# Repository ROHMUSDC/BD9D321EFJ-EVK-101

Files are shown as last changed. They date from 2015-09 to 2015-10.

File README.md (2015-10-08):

# BD9D321EFJ-EVK-101 Design Resource Repository
* Hardware Design Files and Documentation for the ROHM BD9D321EFJ-EVK-101 EVK

----
### Description: 
* BD9D321EFJ is a synchronous buck switching regulator with built-in low on-resistance power MOSFETs
* It is capable of providing current of up to 3 A
* The SLLM (TM) control provides excellent efficiency characteristics in light-load conditions which make the product appropriate for equipment and devices that demand minimal standby power consumption
* External phase compensation circuit is not necessary because this device uses a constant on-time control DC/DC converter with high speed response

----
### Repository Contents
* Application Note Folder: Contains Draft Version of EVK Application Note
* Design Files: Contains Board, Gerber, Schematic, and BOM information for this EVK Board
* Measurement Reports Folder: Contains measurement testing information completed for these EVK Boards

----
### Where to Purchase?
* http://www.rohm.com/web/global/distribution/-/dinventory/BD9D321EFJ-EVK-101/sample/0

----
### DISCLAIMER
This Technical Data is protected under copyright laws.

ROHM hereby grants you a nonexclusive, nontransferable license to use this Technical Data 
as long as you abide by the terms and conditions of this DISCLAIMER. 

However, you are not authorized to sell, loan, rent, lease, redistribute or license this Technical Data, 
in whole or in part, or in modified form, to anyone.

You may modify this Technical Data to suit your specific applications, 
but the rights to derivative works and said modifications shall belong to ROHM. 

You may make copies of this Technical Data as necessary for internal use only within your company.

In any case, the latest datasheet is considered the final design guideline and represents 
the only actual performance specifications.

ROHM shall not be responsible for ensuring proper application on all computer systems.
This Technical Data is provided AS IS. ROHM makes no guarantees, either implicitly or explicitly, 
regarding its usability, functionality, accuracy, merchantability, or fitness for a specific purpose.

In addition, you shall take full responsibility for the use of any information acquired from this Technical Data. 

ROHM does not assume warranty of any kind arising from the use of this Technical Data. ACCORDINGLY, 
IN NO EVENT SHALL ROHM BE RESPONSIBLE, WHETHER THROUGH CONTRACT OR TORT LIABILITY, 
FOR ANY DAMAGES (INCLUDING BUT NOT LIMITED TO LOST PROFITS OR OTHER INCIDENTAL, CONSEQUENTAL, 
OR PUNITIVE DAMAGES) ARISING OUT OF OR IN CONNECTION WITH THE USE OR APPLICATION OF THIS Technical Data.

Furthermore, this Technical Data is subject to change without notice.

Unless otherwise expressly provided herein, ROHM does not convey any license under patent rights 
or any other intellectual property rights (including those of third parties).

ROHM is not obligated to provide maintenance or support for the Technical Data.

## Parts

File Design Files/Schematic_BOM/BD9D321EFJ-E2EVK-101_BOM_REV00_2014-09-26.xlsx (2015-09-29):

BD9D321EFJ-E2EVK-101 BOM
Revision: 00
Item | Quantity | Reference | Part | PCB Footprint | DESCRIPTION | MFG1 | MFG1_PART# | DISTR1 | DISTR1_PART# | DNP | Provided by ROHM | ROHM Comment
1 | 1 | C1 | 100pF | C0603 | CAP CER 100PF 50V 5% NP0 0603 | Murata | GRM1885C1H101JA01D | DIGIKEY | 490-1433-2-ND |  | Y
2 | 2 | C2,C10 | 0.1uF | C0603 | CAP CER 0.1UF 50V 10% X7R 0603 | Murata | GRM188R71H104KA93D | DIGIKEY | 490-1519-2-ND |  | Y
3 | 2 | C3,C4 | 10uF | C1206 | CAP CER 10UF 35V 10% X5R 1206 | Murata | GRM31CR6YA106KA12L | DIGIKEY | 490-5524-1-ND |  | Y
4 | 2 | C5,C6 | 22uF | C1210 | CAP CER 22UF 25V 10% X5R 1210 | Murata | GRM32ER61E226KE15L | DIGIKEY | 490-3889-1-ND |  | Y
5 | 1 | C11 | 1uF | C0603 | CAP CER 1UF 25V 10% X7R 0603 | Murata | GRM188R71E105KA12D | Digikey | 490-5307-2-ND |  | Y
6 | 1 | C12 | 3300pF | C0603 | CAP CER 3300PF 50V 10% X7R 0603 | Murata | GRM188R71H332KA01D | Digikey | 490-1503-2-ND |  | Y
7 | 1 | D1 | SMAJ18A | DO-214AC | DIODE TVS 400W 6.8V UNI 5% SMD | Littelfuse Inc | P4SMA6.8A | DIGIKEY | F5656CT-ND |  | N
8 | 1 | J1 | 87224-3 | HDR_THVT_1X3_100 | CONN HEADER VERT .100 3POS 15AU | TE Connectivity | 87224-3 | DIGIKEY | A26545-ND |  | N
9 | 1 | L1 | 2.2uH | SMT_6P9x6P9 | INDUCTOR POWER 2.2UH 9A SMD | Wurth | 744311220 | DIGIKEY | 732-1151-2-ND |  | Y
10 | 1 | R1 | 30k | R0603 | RES 30K OHM 1/10W 1% 0603 SMD | Rohm | MCR03ERTF3002 | DIGIKEY | RHM30KCFTR-ND |  | Y
11 | 1 | R2 | 22k | R0603 | RES 22K OHM 1/10W 1% 0603 SMD | Rohm | MCR03ERTF2202 | DIGIKEY | RHM22.0KCFTR-ND |  | Y
12 | 1 | R3 | 0 | R0603 | RES 0.0 OHM 1/10W JUMP 0603 SMD | Rohm | MCR03ERTJ000 | DIGIKEY | RHM0.0CGCT-ND |  | Y
13 | 2 | TP1,TP3 | TP_TH_63MIL_RED | TP_TH | TEST POINT PC MULTI PURPOSE RED | Keystone Electronics | 5010 | DIGIKEY | 5010K-ND |  | N
14 | 2 | TP2,TP4 | TP_TH_63MIL_BLK | TP_TH | TEST POINT PC MULTI PURPOSE BLK | Keystone Electronics | 5011 | DIGIKEY | 5011K-ND |  | N
15 | 1 | U1 | BD9D321EFJ | HTSOP-J8 | IC REG BUCK SYNC ADJ 3A 8HTSOP | Rohm | BD9D321EFJ-E2 | Digikey | BD9D321EFJ-E2TR-ND |  | Y
16 | 1 |  |  |  | Shunt jumper for header J1(item #8) CONN SHUNT 2POS GOLD W/HANDLE | TE Connectivity | 881545-1 | DIGIKEY | 881545-1-ND |  | N
17 | 1 | C7 | TBD | C0603 | TBD | TBD | TBD | TBD | TBD | Do Not Place
18 | 1 | C8 | TBD | C0805 | TBD | TBD | TBD | TBD | TBD | Do Not Place
19 | 1 | C9 | TBD | C1206 | TBD | TBD | TBD | TBD | TBD | Do Not Place

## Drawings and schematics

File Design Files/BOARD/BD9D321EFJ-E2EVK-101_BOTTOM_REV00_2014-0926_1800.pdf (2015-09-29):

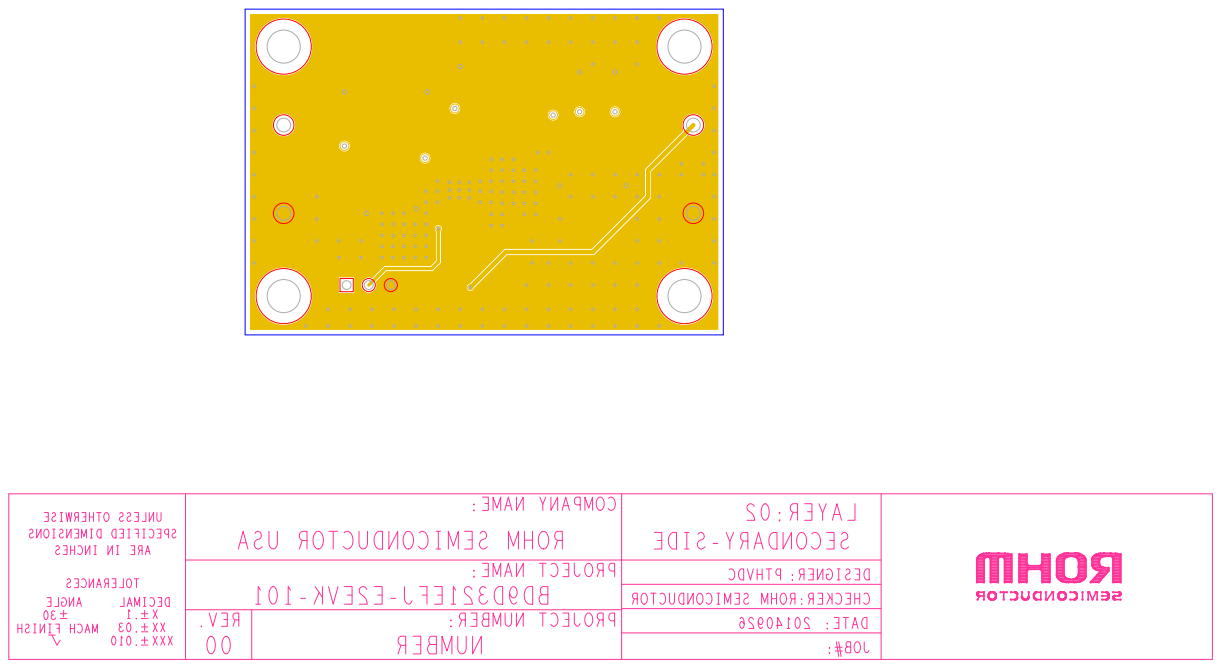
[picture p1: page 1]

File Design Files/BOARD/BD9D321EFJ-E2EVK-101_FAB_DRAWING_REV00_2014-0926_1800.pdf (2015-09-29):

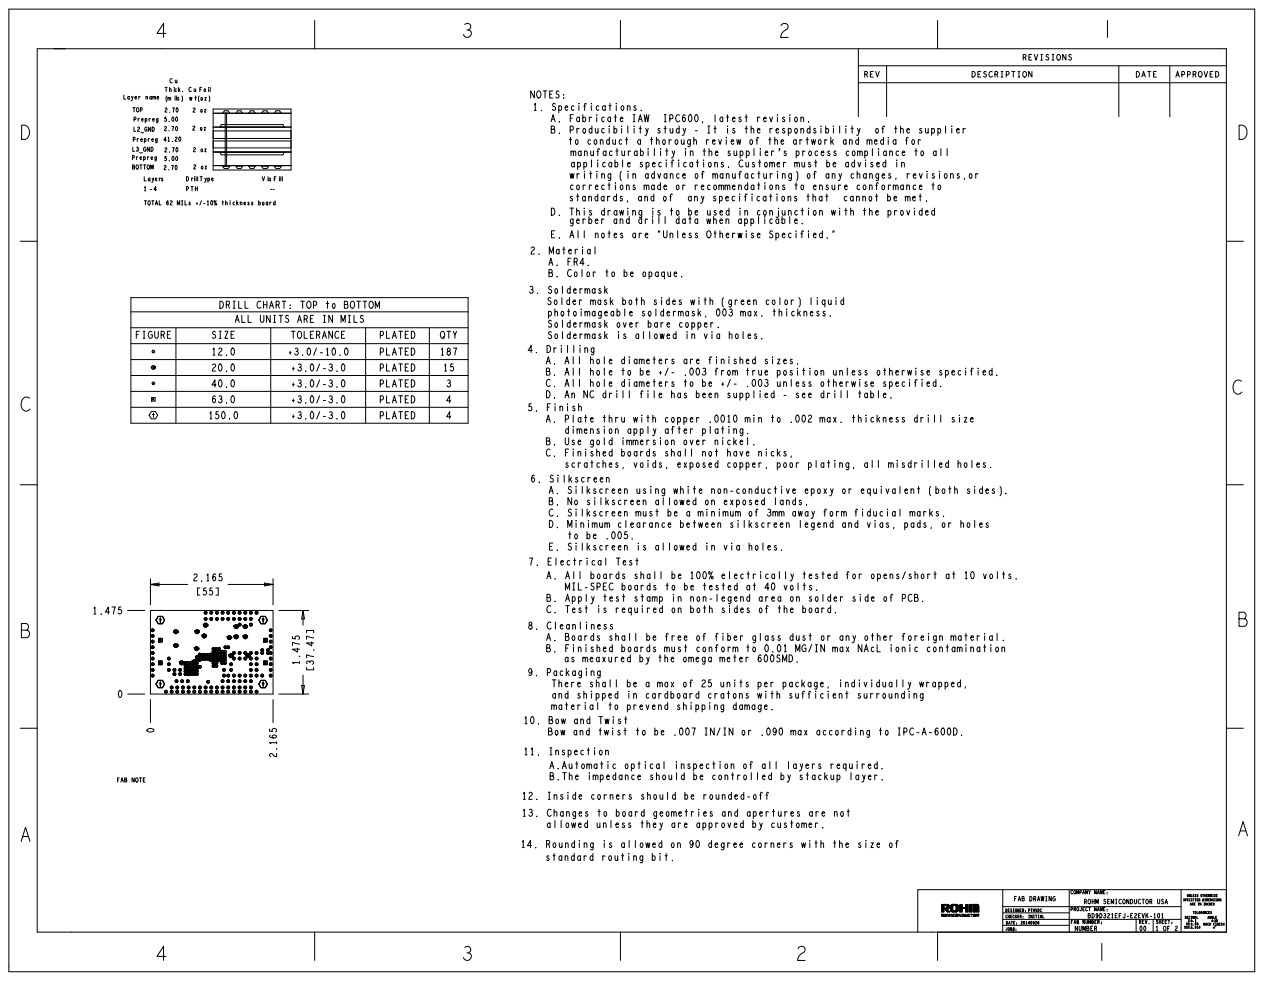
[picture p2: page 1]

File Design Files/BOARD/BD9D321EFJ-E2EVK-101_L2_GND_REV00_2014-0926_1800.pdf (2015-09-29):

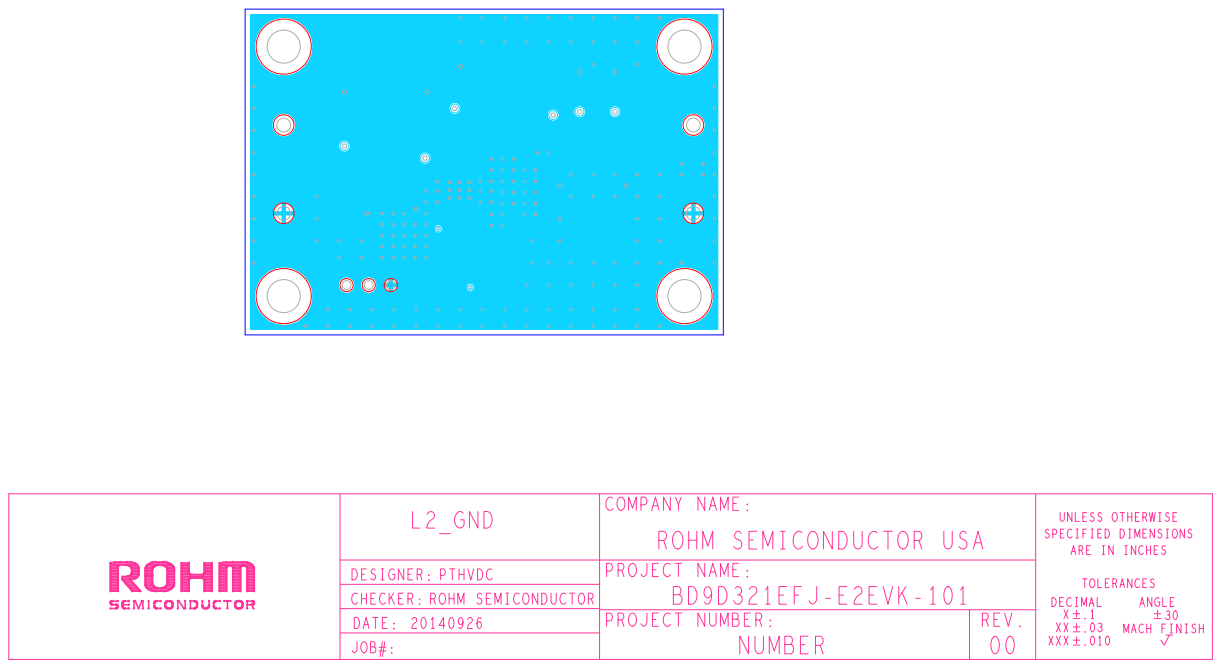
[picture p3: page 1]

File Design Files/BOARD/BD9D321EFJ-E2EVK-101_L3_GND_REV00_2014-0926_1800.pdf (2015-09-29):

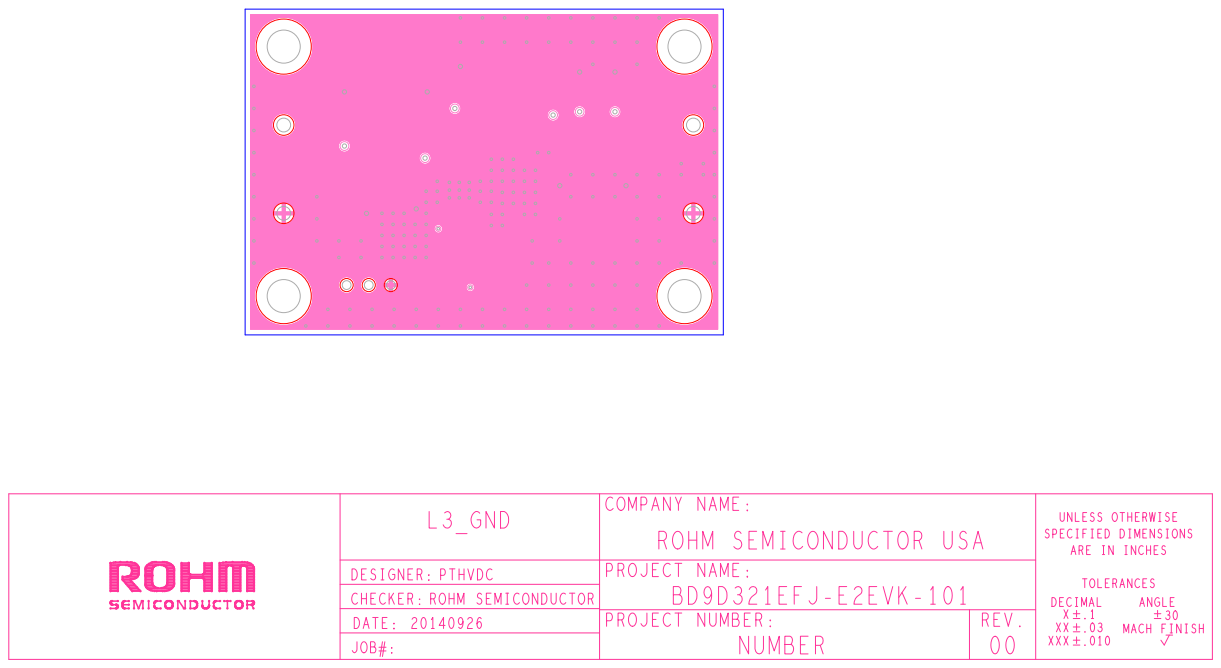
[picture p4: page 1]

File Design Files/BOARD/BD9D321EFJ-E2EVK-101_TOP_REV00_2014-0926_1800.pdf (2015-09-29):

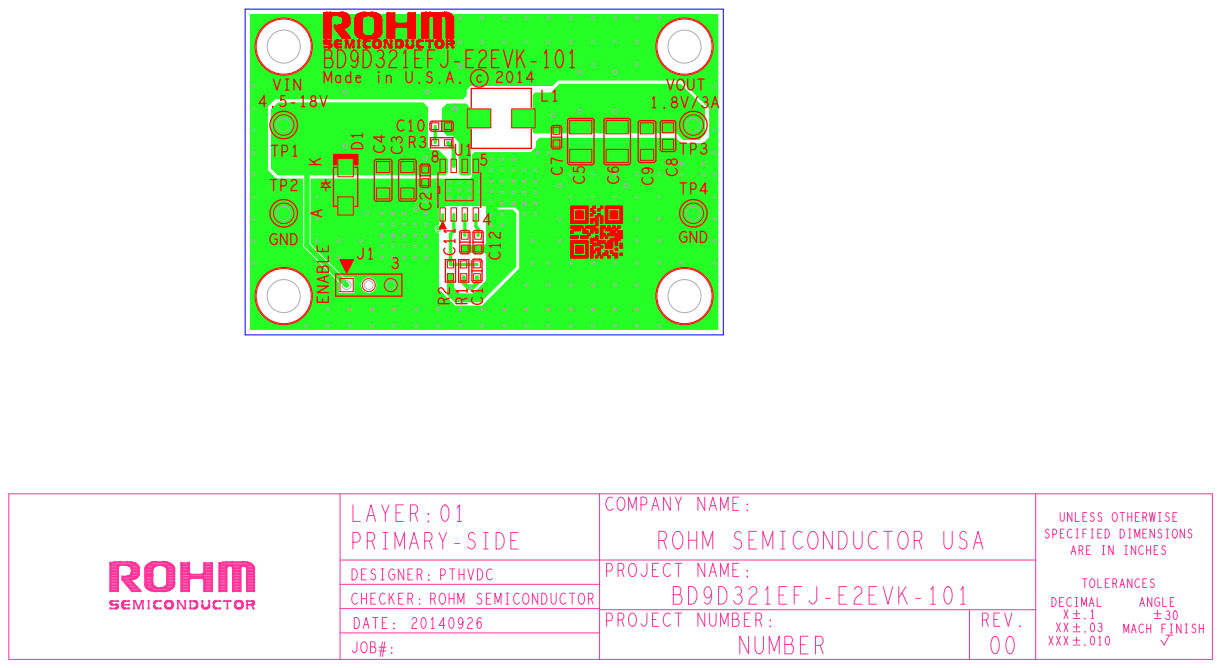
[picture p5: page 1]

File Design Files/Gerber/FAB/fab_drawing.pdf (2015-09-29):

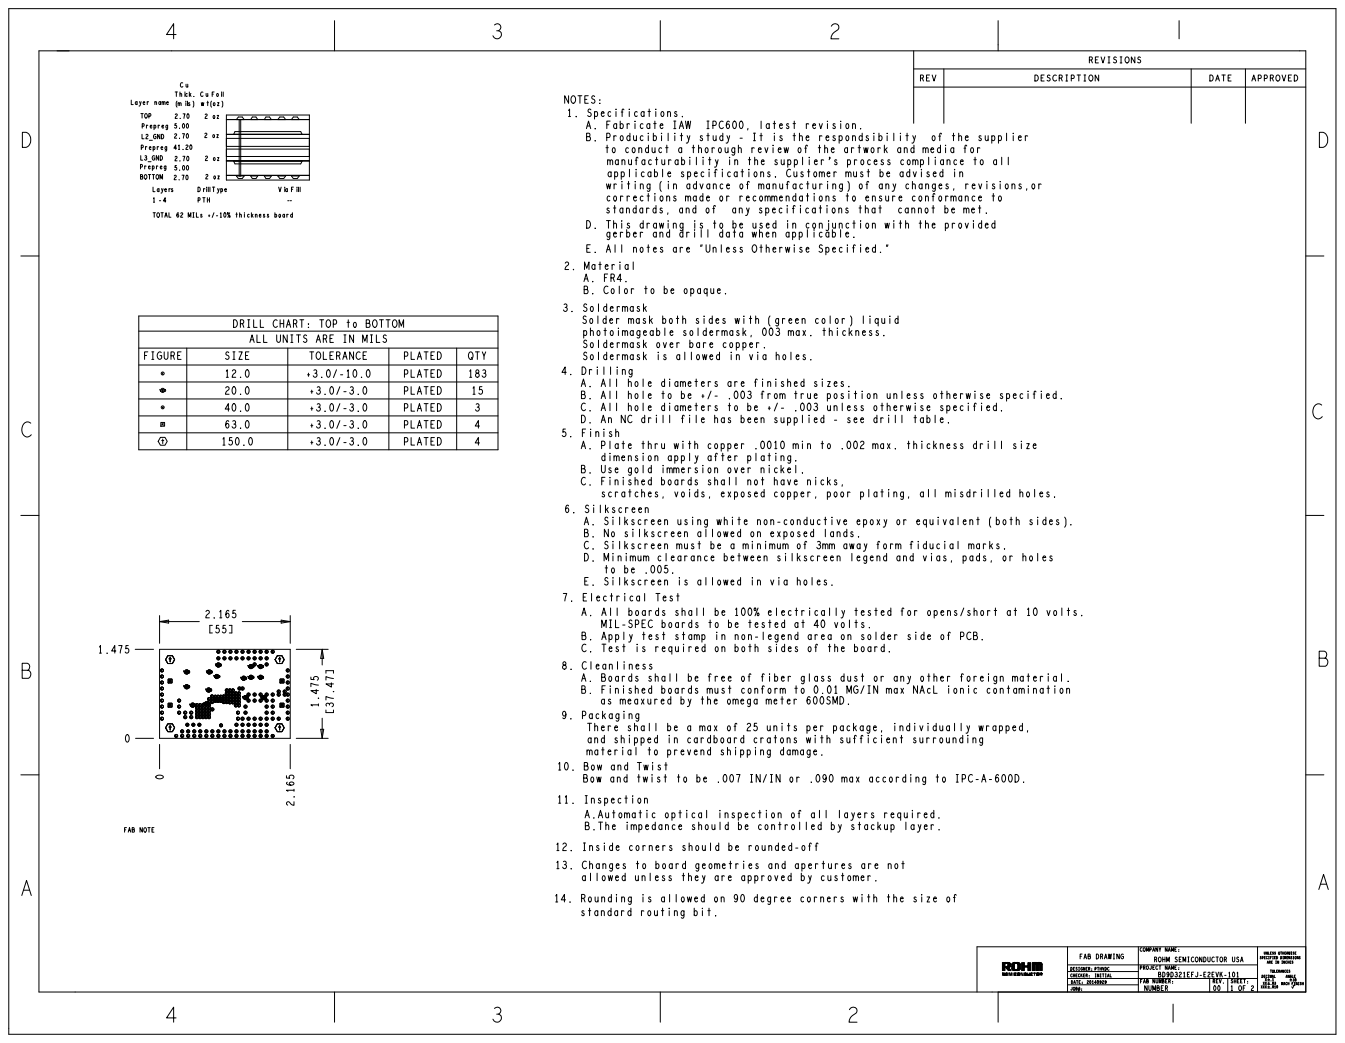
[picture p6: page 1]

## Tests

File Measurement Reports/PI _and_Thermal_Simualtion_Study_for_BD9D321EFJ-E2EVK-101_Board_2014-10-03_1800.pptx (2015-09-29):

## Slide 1

PI and Thermal Simulation Study for BD9D321EFJ Board
October 03^r^d, 2014
Hosted by: Xuan Dang

PTH Solutions Confidential

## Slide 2

Agenda
  I. Introduction
  II. DC Drop Analysis
  III. Current Density Analysis
  IV. Thermal Analysis
  V. Conclusion

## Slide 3

Introduction

1. This work considers power simulation and thermal simulation on BD9D321EFJ boards.
  - Based on board file BD9D321EFJ-E2EVK-101_BRD_REV00_2014-09-29.brd
2. PowerDC software is used for simulation
3. PI simulation considers:
  a. DC Drop analysis
    - Determine what the max drop for power rail
  b. Current Density analysis
    - Determine the hot spot of current density on PCB
4. Thermal simulation considers:
    - PCB temperature profile including consideration for conductive, radiative, and convective heat transfer

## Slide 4

BD9D321EFJ Board

- Based on the board file : BD9D321EFJ-E2EVK-101_BRD_REV00_2014-09-29.brd

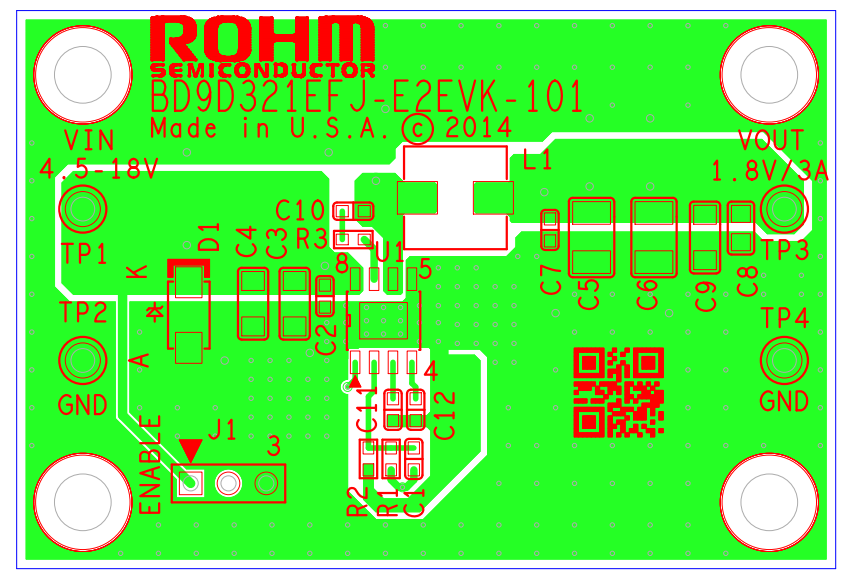
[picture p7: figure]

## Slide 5

BD9D321EFJ Schematic

Based on the schematic file : BD9D321EFJ-E2EVK-101_SCH_REV00_2014-09-26.pdf

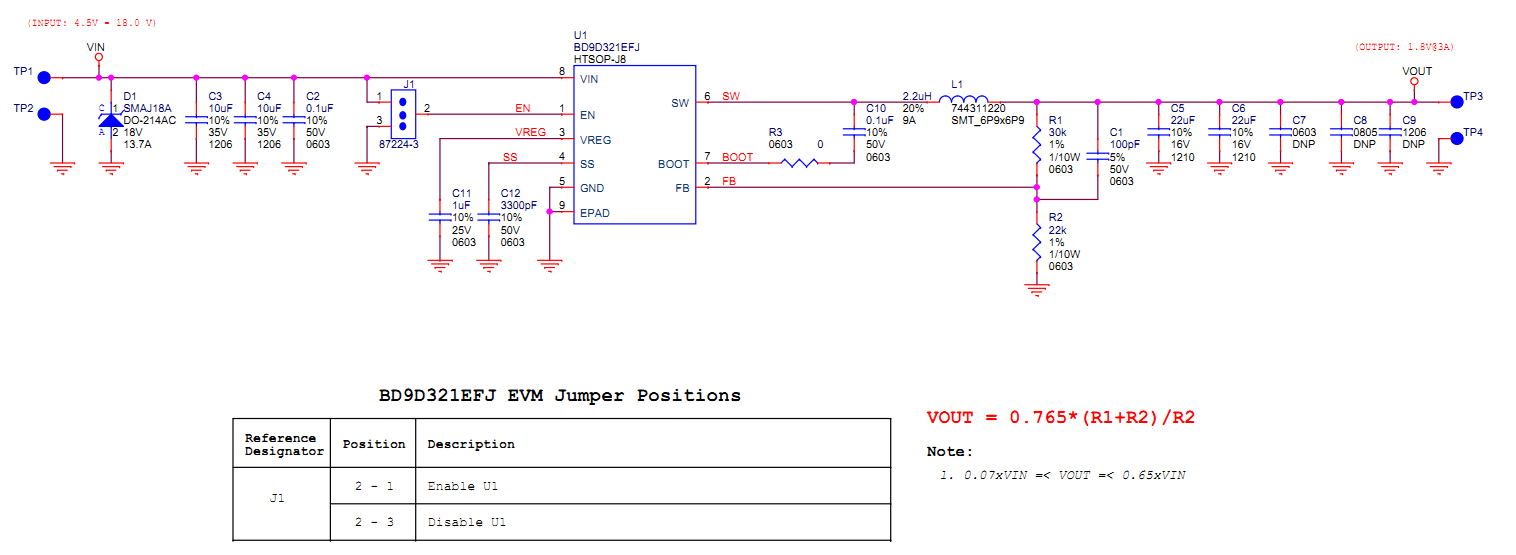
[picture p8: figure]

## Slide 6

BD9D321EFJ Board power consumption

Device/rail | Source/VRM refdes | Source PCB netname | Sink/load PCB refdes | Load PCB net name | Nominal Voltage(V) | Voltage tolerance (%) | Max current (A) | Power input (W) | Power consumption (W) | Note
Power input via TP1/TP2 connectors (VIN 4.5-18V) | TP1 | VIN | U1 | VIN | 4.5 | | 2 | 9.0 | | Max input current = (Pout + PONH + PONL + PL)/VIN = 1.55A with Vin= 4.5 V. So we choose max input current = 2A to simulate power/thermal
Power dissipation on BD9D321EFJ internal FETs | TP1 | VIN | U1 | VIN | 4.125 | | 3 | | 1.476 | RONH = 0.2 Ohm; RONL = 0.14 Ohm
Power dissipation on inductor L1 | U1 | SW | L1 | SW | | | 3 | | 0.1026 | RL = 0.0114 Ohm
Power consumption at load via connector TP3/TP4 (VOUT 1.8V) | L1 | SW | TP3 | VOUT | 1.8 | 2 | 3 | | 5.4
| | | | | | | Total | 9.0 | 6.9786

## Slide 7

DC Drop analysis for VIN 4.5V@2A at TOP Layer

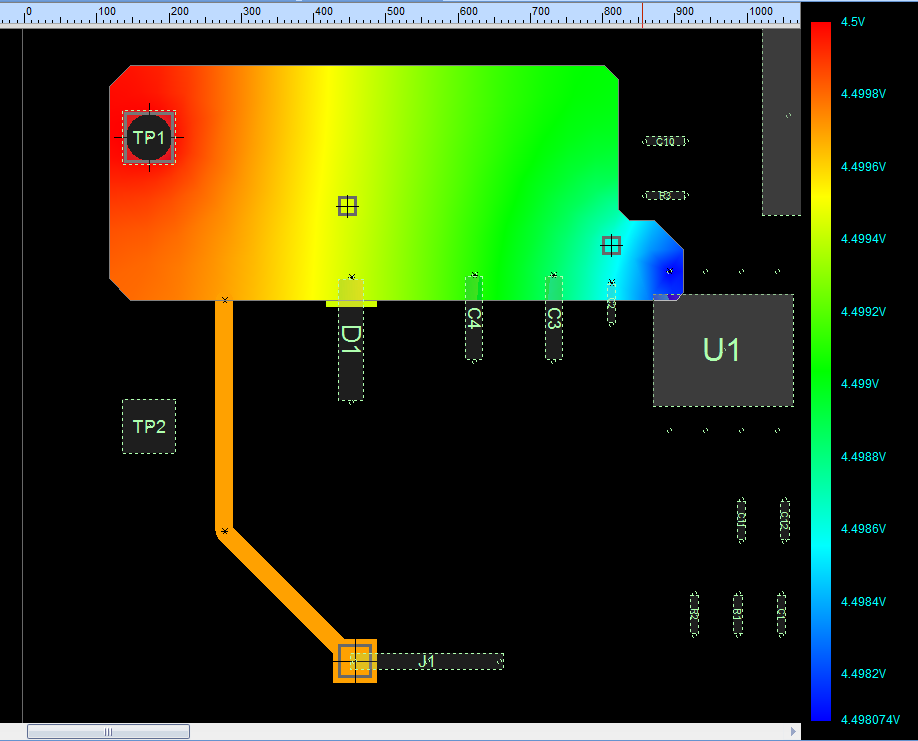
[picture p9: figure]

Max DC Drop 1.93mV < 90 mV (2% tolerance of 4.5V) → Copper planes for VIN is OK

Source TP1

Load U1

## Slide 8

Current Density analysis for VIN 4.5V@2A at TOP Layer

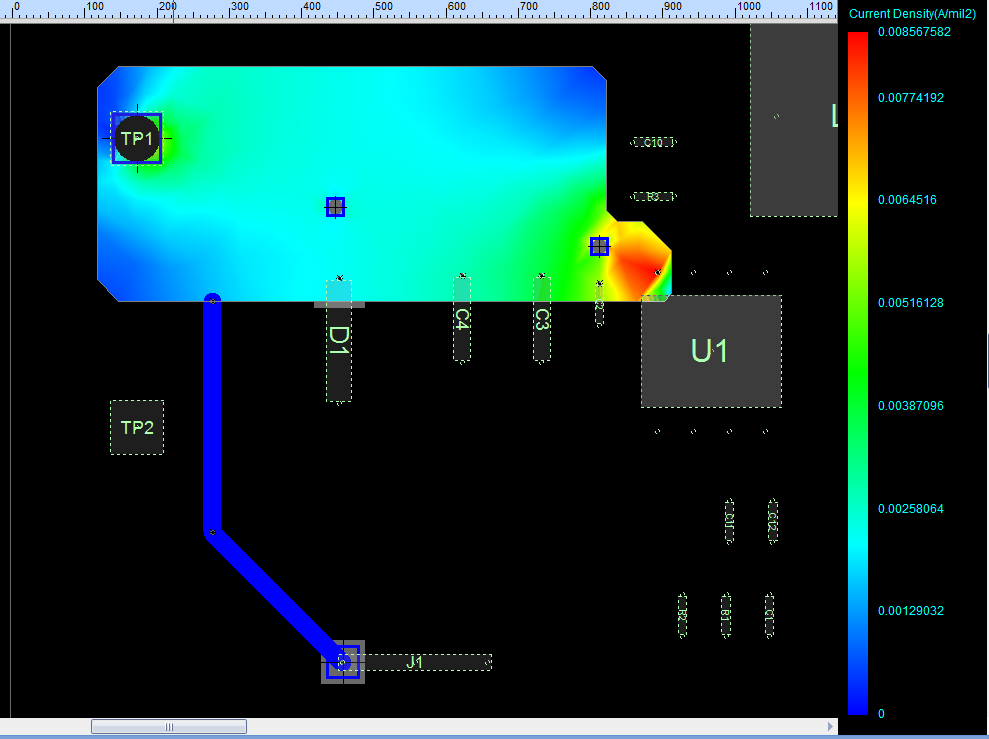
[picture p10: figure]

Source TP1

Load U1

Max Current Density 8.57mA/mil²<40mA/mil² (This rule limit 10 Celsius degree of temperature rise above ambient) → Copper plane for VIN is OK

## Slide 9

DC Drop analysis for VOUT@3A at TOP layer

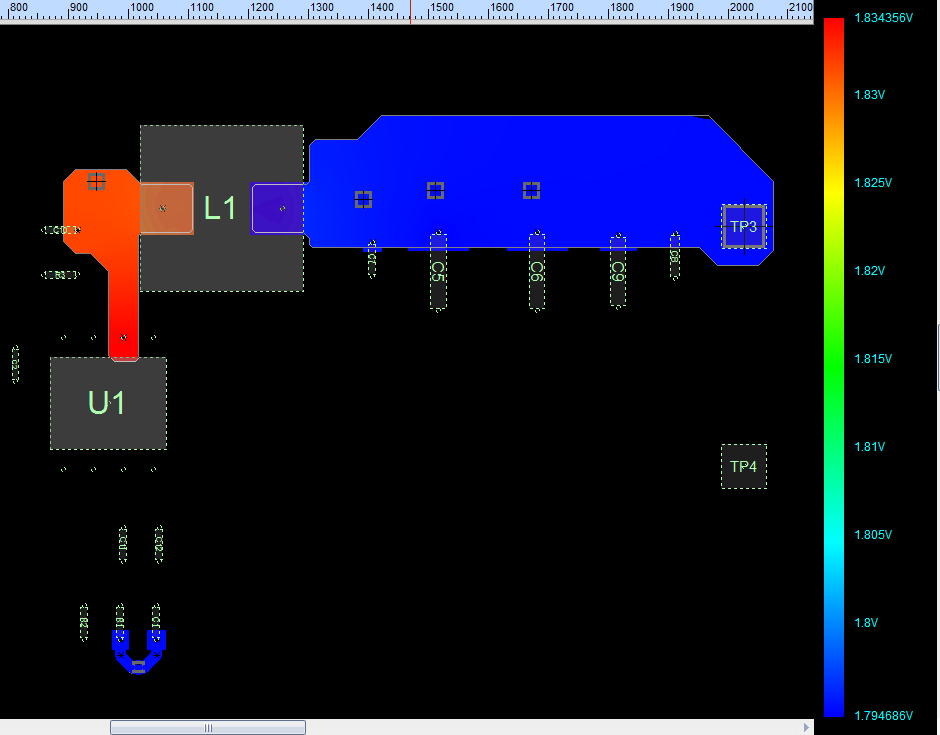
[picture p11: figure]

Max DC Drop 5.3mV < 36mV (2% tolerance of 1.8V) → Copper planes for VOUT is OK

Source L1

Load TP3

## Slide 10

Current Density analysis for VOUT@3A at TOP layer

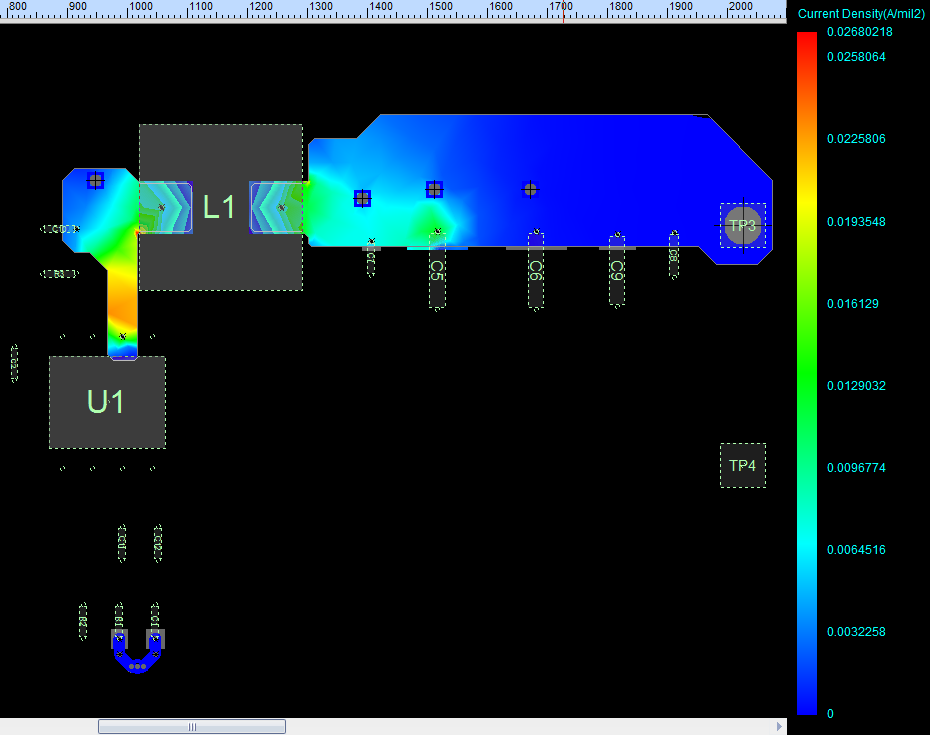
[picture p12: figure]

Source L1

Load TP3

Max Current Density 26.8mA/mil²<40mA/mil² (This rule limit 10 Celsius degree of temperature rise above ambient) → Copper plane for VIN is OK

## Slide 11

Thermal Analysis

a. Environment conditions
  a. Air Temperature : 25 ⁰C , 35 ⁰C and 45 ⁰C
  b. No incoming air flow (Natural convection)

VOUT 20mV/div (AC)

SW 5V/div

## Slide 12

Thermal Analysis (Con’t)

b. Component properties

| BD9D321EFJ (U1) | 744311220 (L1)
Number of pins | 9 | 2
Max. power dissipation | 1.476 W (at VIN=4.5V) | 0.1026 W

VOUT 20mV/div (AC)

SW 5V/div

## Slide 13

Thermal Analysis (Con’t)

Air temperature 25⁰C, power dissipation of BD9D321EFJ is 1.476 W (at VIN=4.5V)

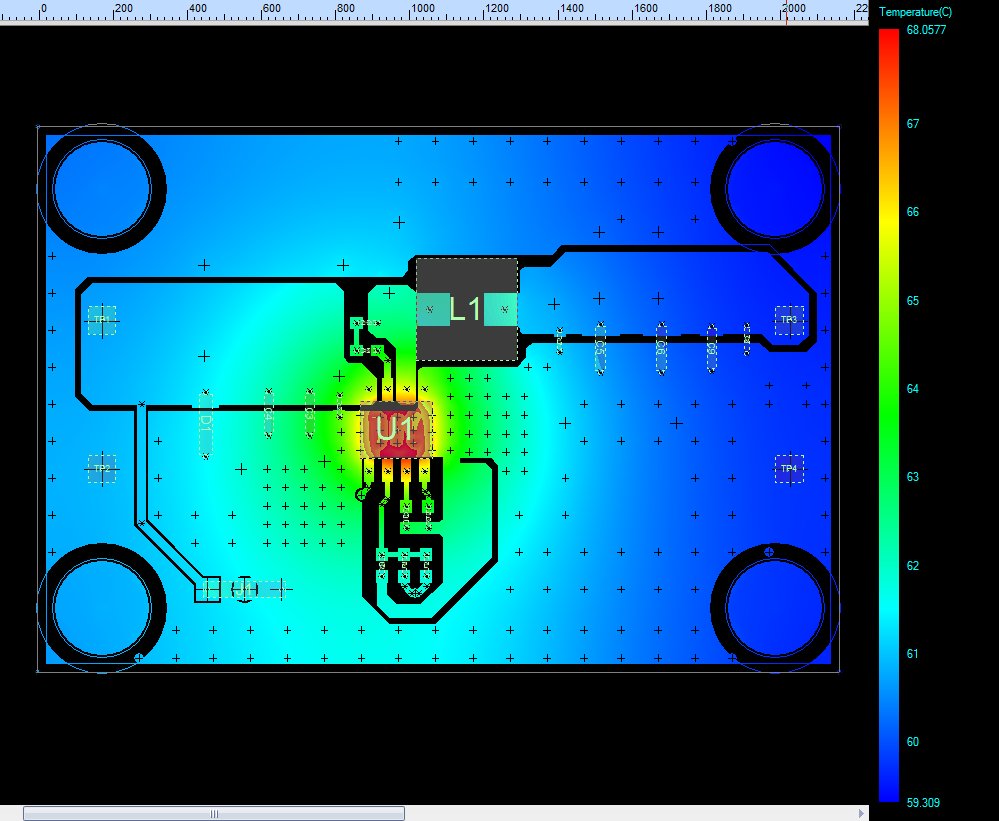
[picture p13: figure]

The highest temperature on board is about 68.06 ⁰C
The highest temperature on component is on BD9D321EFJ( about 68.06 ⁰C)

U1: BD9D321EFJ
- Max. power dissipation: 0.1476 W @VIN=4.5V
- Component temperature = 68.06 ⁰C

L1: 744311220
- Max. power dissipation: 0.1026 W
- Component temperature = 62.46 ⁰C

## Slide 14

Thermal Analysis (Con’t)

Air temperature 35⁰C, power dissipation of BD9D321EFJ is 1.476 W (at VIN=4.5V)

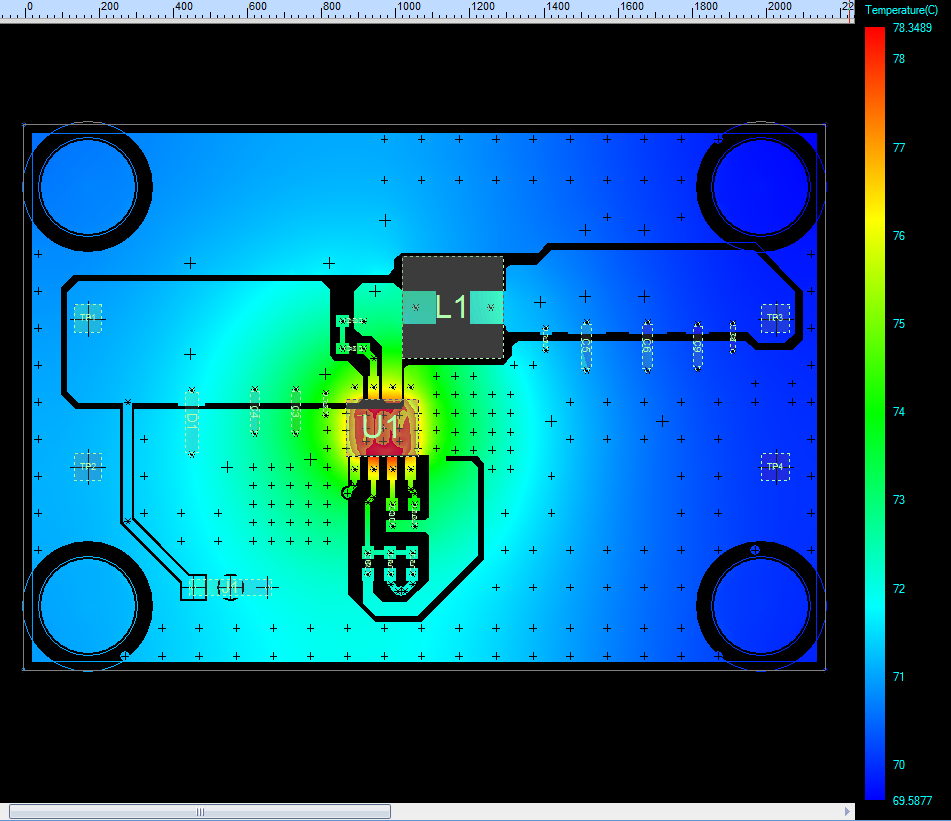
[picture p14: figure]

The highest temperature on board is about 78.35 ⁰C
The highest temperature on component is on BD9D321EFJ ( about 78.35 ⁰C)

U1: BD9D321EFJ
- Max. power dissipation: 1.476 W @VIN=4.5V
- Component temperature = 78.35 ⁰C

L1: 744311220
- Max. power dissipation: 0.1026 W
- Component temperature = 72.65 ⁰C

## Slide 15

Thermal Analysis (Con’t)

Air temperature 45⁰C, power dissipation of BD9D321EFJ is 1.476 W (at VIN=4.5V)

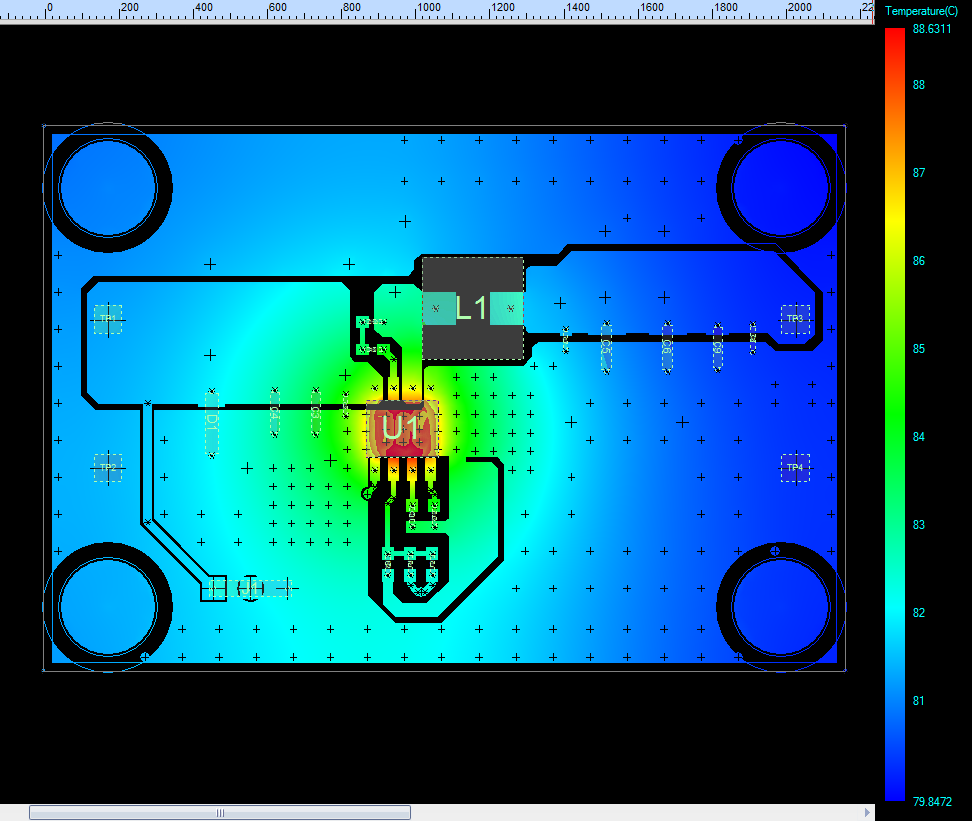
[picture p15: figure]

The highest temperature on board is about 88.63 ⁰C
The highest temperature on component is on BD9D321EFJ ( about 88.63 ⁰C)

U1: BD9D321EFJ
- Max. power dissipation: 1.476 W @VIN=4.5V
- Component temperature = 88.63 ⁰C

L1: 744311220
- Max. power dissipation: 0.1026 W
- Component temperature = 82.96 ⁰C

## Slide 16

Summary

1. The PI simulation shows that the max. amount voltage drop of VIN power is 1.93mV, the max. current density of VIN power is 8.57mA/mil²; the max. amount voltage drop of VOUT power is 5.3mV, the max. current density of VOUT power is 26.8mA/mil²
2. The highest temperature of BD9D321EFJ-E2EVK-101 board can be reached temperature as table below:

| VIN=4.5V
Air temperature: 25⁰C | 68.06 ⁰C
Air temperature: 35⁰C | 78.35 ⁰C
Air temperature: 45⁰C | 88.63 ⁰C
